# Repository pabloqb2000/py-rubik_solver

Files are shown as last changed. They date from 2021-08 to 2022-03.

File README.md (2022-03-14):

# Python solver for a rubik's cube
This project implements the logic for recognizing, storing, solving and visualizing a cube.

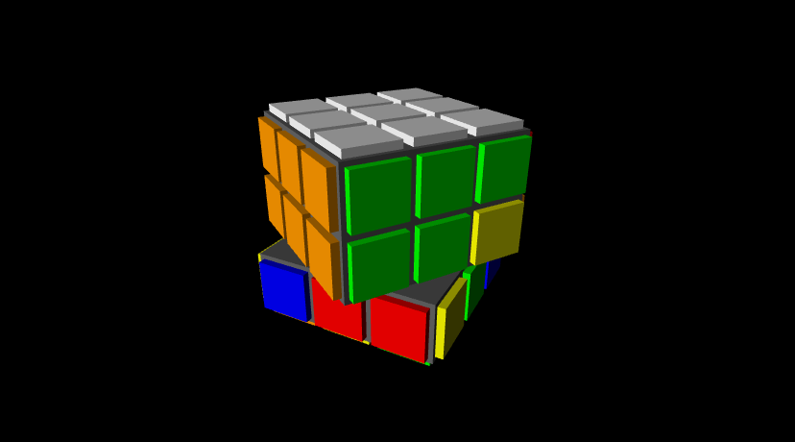
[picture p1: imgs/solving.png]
solving the cube image


## Robot

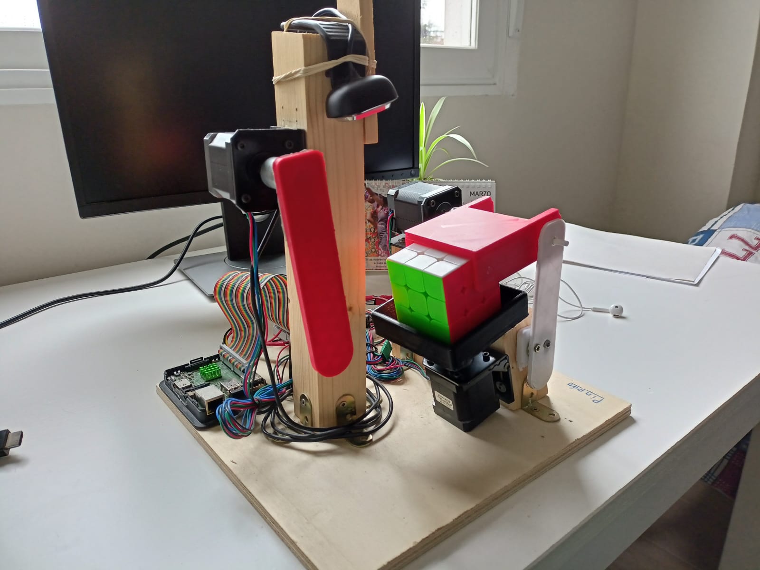
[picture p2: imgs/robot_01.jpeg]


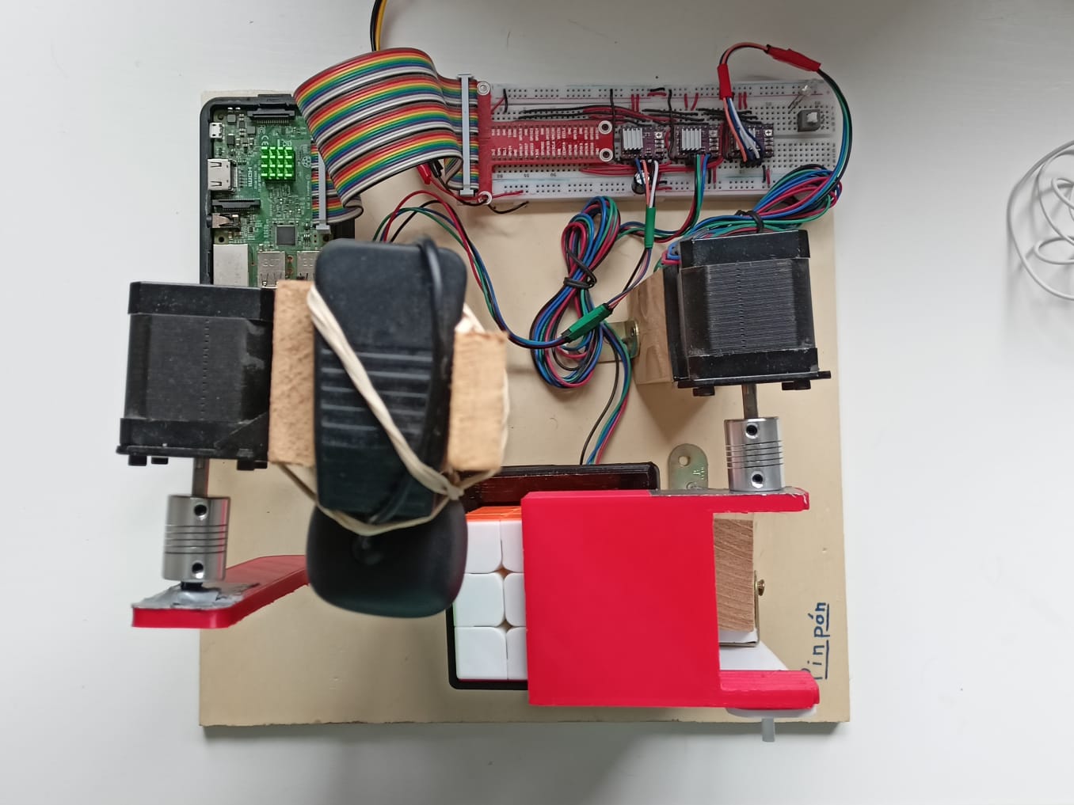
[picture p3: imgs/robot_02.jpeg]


## Demo

You can see the robot in speed up action here:

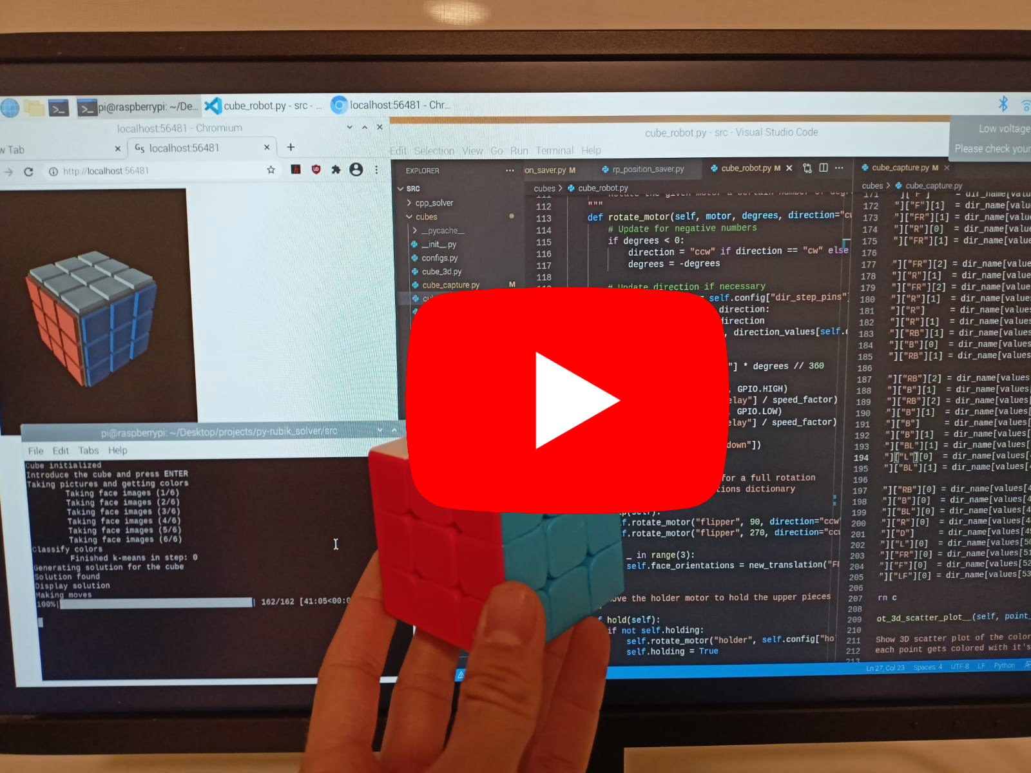
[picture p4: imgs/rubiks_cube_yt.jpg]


Or die whatching the raw full 43 minutes it takes to fully solve the cube here:

<a href="https://www.youtube.com/watch?v=FDxR2-XFLAM">Speed up video</a>

## Table of contents
- [Python solver for a rubik's cube](#python-solver-for-a-rubik-s-cube)
  * [Robot](#robot)
  * [Demo](#demo)
  * [Usage](#usage)
  * [Requirements](#requirements)
  * [Implementation](#implementation)
  * [Cubes directory](#cubes-directory)
    + [configs.py](#configspy)
    + [cube.py](#cubepy)
    + [cube_3d.py](#cube_3dpy)
    + [cube_capture.py](#cube_capturepy)
    + [cube_robot.py](#cube_robotpy)
    + [util.py](#utilpy)
  * [Saved positions directory](#saved-positions-directory)
  * [Solvers directory](#solvers-directory)
    + [cube_solver.py](#cube_solverpy)
    + [simple_solver.py](#simple_solverpy)
    + [simple_solver_2.py](#simple_solver_2py)
    + [iddfs.py](#iddfspy)
    + [thistlethwaite_solver.py](#thistlethwaite_solverpy)
  * [Hardware and wiring](#hardware-and-wiring)
  * [Appendix](#appendix)
  * [Notes](#notes)

## Usage
To use this program you need to execute the following commands inside de `src` folder
- For detecting the cube colors from a web cam and solving the cube:

    ```python detect_and_solve.py```
- For visualizing a solution of a randomly scrambled cube:

    ```python visualizer.py```
- For getting some statistics:

    ```python stats.py```
## Requirements
This project has been developed in _python 3.8.10_ but there is no reason it shouldn't work in _python 3.7_ or later.
You will also need a recent version of _numpy_, _tqdm_ and _vpython 7_ or later, those can be installed with:

```pip install numpy vpython tqdm```

## Implementation

This project is divided in three different directories:
- **cubes/** which contains all the logic for storing, visualizing and moving a cube
- **saved positions/** used to calibrate the raspberry pi camera
- **solvers/** where I store the different solvers I've implemented

And three main files:
- **detect_and_solve.py**: used to detect a cube with a webcam, find a solution and move the cube to finally solve it.
- **stas.py**: used to calculate some statistics about the different solvers, their speeds and the average number of total moves used.
- **visualizer.py**: used to scramble a virtual cube, find a solution and display the cube and the moves until the cube gets solved. 

## Cubes directory
### configs.py
This file contains general configuration parameters mostly related to the **default** visual representation of the cube:
- The default colors
- The number of fps
- The time taken to reproduce each move
- Time to wait between moves
- Speed factor
- And more

### cube.py
This file contains the ```Cube``` class, which implements a data structure for storing the pieces of the cube and some functions for rotating the faces of the cube. It also implements the possibility to shuffle the cube on creation and the possibility of recording a list of moves made in the cube, this is used for generating a solution.

The main functions implemented in this class are:
- ```move(move, n=1, record=True)```: where _move_ should be a string representing the face to move and _n_ is the number of 90 degree rotations to perform (2 is half turn and 3 or -1 is a turn to the other side). The codes used for the _move_ are:
    - _"U", "F", "R", "B", "L", "D"_ for individual faces.
    - _"UD", "FB", "RL"_ for the middle faces.
    - _"UU", "FF", "RR"_ for rotations of the whole cube along this axis.
    
- ```rotate(axis, n=1)```: this has the same effect as using ```move``` with _"UU", "FF", "RR"_ but these moves are never recorded.
- ```is_solved()```: checks whether the cube equals the solved cube. Keep in mind that this function will return ```False``` even if the cube is solved but faces a different way.
- ```copy()```: creates a _deep_copy_ of the cube. The copy is completely independent of the original cube.

### cube_3d.py
This file implements the ```Cube3D``` class, which directly inherits from the ```Cube``` class. This class overrides the ```__init__``` and ```move``` functions to first create all the cubes necessary to represent the rubiks cube in 3D and then animate them each time any face is moved.

### cube_capture.py
This file contains:
- An implementation for the `k_means` algorithm. This is an **unsupervised learning algorithm** used to classify the colors of the 54 stickers of the cube and separete them in 6 groups of 9 colors each, one group for each face.
- The ```CubeCapture``` class, which contains the logic for capturing the cube using the raspberry pi motors and webcam. The main method this class contains is the ```capture_cube``` method, this method takes care of calling the appropiate methods for:
    - Rotating the cube and taking the photos
    - Extract the colors from the center of the faces in the photos
    - Plot this colors on a 3D scatter plot if debug mode is enabled
    - Classify this colors using the `k_means` algorithm in 6 groups
    - Generate a cube structure from this classification of the colors

### cube_robot.py
This file contains the `CubeRobot` class, used to setup and move the motors on the raspberry pi. It encapsulates the motors movements in the method `move`, which is equivalent to the method move of the `Cube` class.

It also contains some configuration parameters related to the physical robot, like the numbers of the pins the motors are connected to, the speed of the movements and more.

### util.py
In this file we store different _lists_ and _dictionaries_ used in the project such as a solved cube structure, a list of the directions, a _function_ for generating random moves, ...

## Saved positions directory
This directory is simple, it just contains the `position_saver.py` file, which is used to calibrate the position of the faces seen by the camera. You just run it from the main folder with `python saved_positions/position_saver.py`, double click on the center of each piece, hit `space` to save the changes to `position_01.npy` and hit `Esc` to quit.

## Solvers directory
### cube_solver.py
This file implements the ```CubeSolver``` class, which acts as an abstract class for all the other solving algorithms. It only takes care of taking some measures for statistics.
### simple_solver.py
This is the first solving algorithm implemented, it's the usual _beginer_ algorithm for anyone learning how to solve the rubiks cube. It's implemented on a really naive way, and it's far from optimal in terms of the number of steps of the solution. It was just a proof of concept and my goal is to implement a better, more efficient version of this class in the future.

In my personal computer this algorithm takes ```1.78 ms``` on average to compute a solution, and the solutions have ```205.6``` steps on average. Again these results are far from good, but this was just a proof of concept.

The process of the algorithm is separated in different steps, which are:
- *solve_first_cross*: solves the cross on the _UP_ face
- *solve_first_corners*: solves the corners on the _UP_ face
- *solve_second_row*: solves the second _"crown"_ or the second row
- *solve_second_cross*: creates a cross on the _DOWN_ face
- *orientate_2nd_cross*: positions correctly the pieces inside the cross on the _DOWN_ face
- *solve_second_corners*: positions correctly the corners in the _DOWN_ face
- *orientate_2nd_corners*: rotates correctly the corners in the _DOWN_ face
- *reorient_cube*: rotates the whole cube so that the _UP_ face is facing up and the _FRONT_ face if facing front

### simple_solver_2.py
This file implements an optimization of the `simple_solver`, it just takes the `simple_solver` solution, eliminates the full cube rotations and simplifies the movements that can be unified.

### iddfs.py
This file just implements _iterative deepening depth first search_, a path finding algorithm to find the fastests secuences of moves that should be taken to reach a goal. This is a brute force algorithm and it would take ages to find the fastest solution for a cube, instead this is used by the thistlethwaite's algorithm.

### thistlethwaite_solver.py
More information about how this algorithm works can be found in the references.

This is an unfinished file, my idea was to implement this algorithm, but after some testing, python is too slow to run this algorithm in a reasonable amount of time. That's why I decided to implement a cpp version of this algorithm, but the cpp version just didn't work on the final step so, since I was running out of time, I decided to keep the naive raw `simple_solver` approach. Of course anyone is encouraged to try an implement the test functions for the first 3 solving groups.

## Hardware and wiring
<img src="https://raw.githubusercontent.com/pabloqb2000/py-rubik_solver/main/imgs/robot_03.jpeg" alt="Speed up video" width="500"/>

For this project I used:
- A Raspberry pi 3 model B v1.2
- 3 stepper motors (17HS19-2004s1)
- 3 step motor drivers (DRV8825)
- A usb webcam
- A 12V power supply for the motors
- A 100uF capacitor
- A breadboard and wires
- Some adaptors to connect the motors to the pieces
- 3D printed parts (available in the **stl/** directory)
- Wood and screws

For the wiring I followed this 2 tutorials:
- [How to fully set up each motor](https://www.rototron.info/raspberry-pi-stepper-motor-tutorial/)
- [How to connect multiple motors](https://forum.pololu.com/t/controlling-two-stepper-motors-with-two-ics-and-one-raspberry-pi-3b/16428/3)

## Appendix

Interesting video on rubik's cube solving algorithms [https://www.youtube.com/watch?v=ZtlMkzix7Bw](https://www.youtube.com/watch?v=ZtlMkzix7Bw)

The implementation the guy on the video made [https://github.com/benbotto/rubiks-cube-cracker](https://github.com/benbotto/rubiks-cube-cracker)

His medium post [https://medium.com/](https://medium.com/@benjamin.botto/sequentially-indexing-permutations-a-linear-algorithm-for-computing-lexicographic-rank-a22220ffd6e3)

Further information aboutn the thistlethwaite algorithm can be found in his GitHub readme, and post.

The idea for the robot I got it from [here](https://www.youtube.com/watch?v=awxGJ7aVk4g)

## Notes
There obviously are more efficient data structures to store the cube, faster algorithms to solve it, better physical robots. This is just the approach I found most intuitive and the one I decided to take the challenge and actually code it. **Any improvement on this code and design is more than wellcome**. 

Use this code as you wish, just let me know if you do, **I'll love to hear what you are up to!**

If you have any _doubts/comments/suggestions/anything_ please let my know via email at ```polqb2000@gmail.com``` or at the email in my profile.

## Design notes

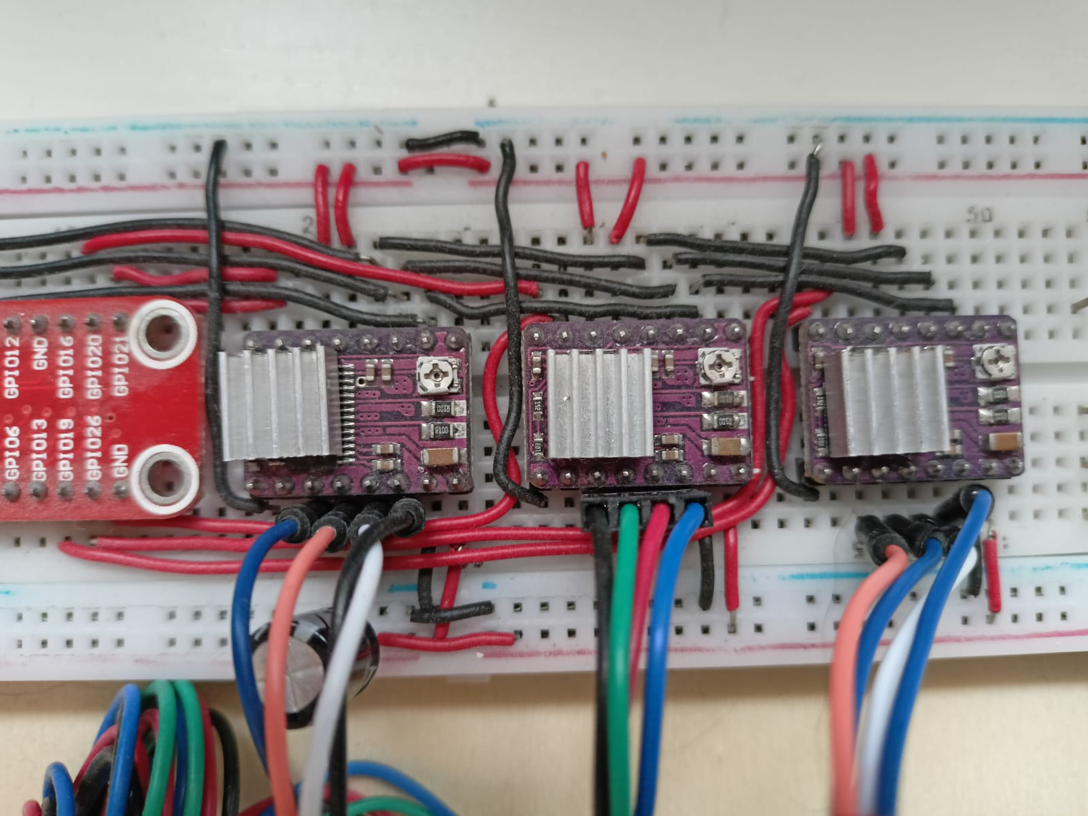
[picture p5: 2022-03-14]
imgs/robot_03.jpeg

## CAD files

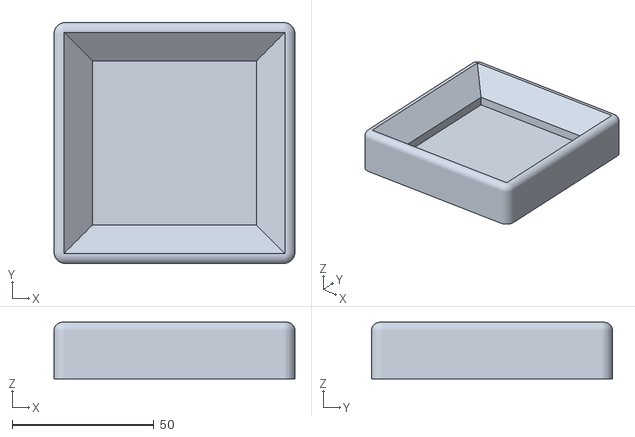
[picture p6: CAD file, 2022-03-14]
stl/Plate.stl
85.0 x 85.0 x 20.0

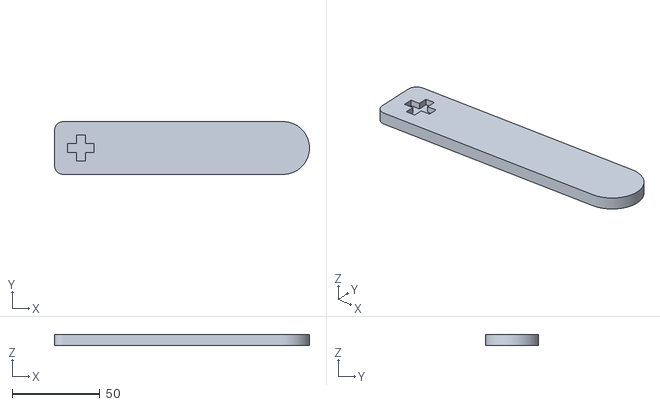
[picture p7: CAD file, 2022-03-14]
stl/Fliper.stl
145.0 x 30.0 x 6.00

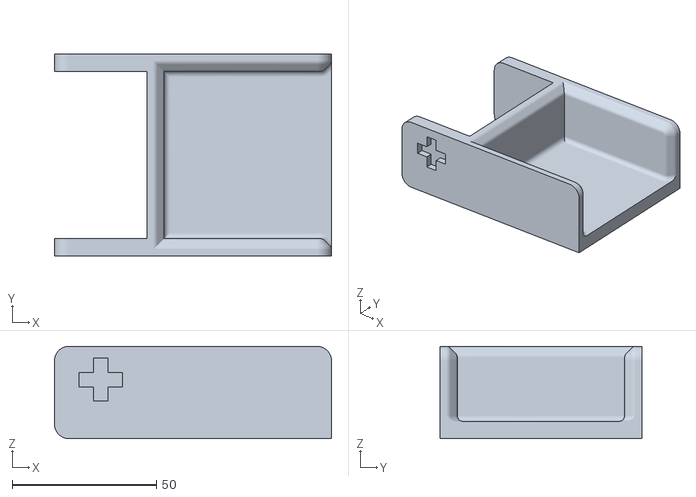
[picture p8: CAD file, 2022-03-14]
stl/Holder.stl
96.0 x 70.0 x 32.0

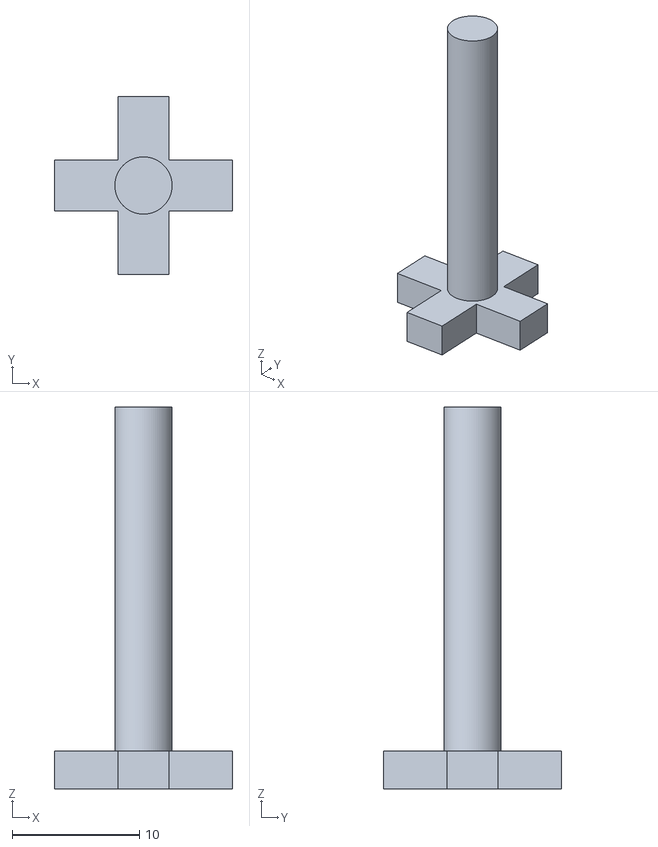
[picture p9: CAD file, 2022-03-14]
stl/Stick.stl
14.0 x 14.0 x 30.0

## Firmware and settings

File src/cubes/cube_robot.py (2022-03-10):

from cubes.util import *
import RPi.GPIO as GPIO
from time import sleep

resolution_values = {1:  (0, 0, 0),
                     2:  (1, 0, 0),
                     4:  (0, 1, 0),
                     8:  (1, 1, 0),
                     16: (0, 0, 1),
                     32: (1, 0, 1)}
motors = ["plate", "holder", "flipper"]
direction_values = {
    "cw": 1,
    "ccw": 0,
}

default_config = {
    "spr": 200,
    "base_delay": 0.0208 / 8,
    "cool_down": 0.1,
    "mode_pins": (14, 15, 18),
    "dir_step_pins": {
        "plate":   (16, 26),
        "holder":  (13, 19),
        "flipper": (20, 21),
    },
    "flip_speed": 0.05,
    "extra_plate_turn": 4,
    "extra_hold_turn": 6,
    "resolution": 32,
    "holder_degrees": 80,
    "holder_direction": "cw",
}

def inv(dir):
    return dir+'P' if dir[-1] != 'P' else dir[:-1]

def new_translation(dir, translate_dict):
    """
        Auxiliary function for the eliminate rotations function
        it returns the appropriate update for the translation dictionary
        given a rotation
    """
    new_translate_dict = translate_dict.copy()

    dir_new, n = translate_dict[dir], 3 if len(translate_dict[dir]) > 2 else 1
    d = dir_new[:2]

    if dir == "UU":
        new_translate_dict["RR"] = translate_dict["FF"]
        new_translate_dict["FF"] = inv(translate_dict["RR"])
    elif dir == "FF":
        new_translate_dict["UU"] = translate_dict["RR"]
        new_translate_dict["RR"] = inv(translate_dict["UU"])
    elif dir == "RR":
        new_translate_dict["UU"] = translate_dict["FF"]
        new_translate_dict["FF"] = inv(translate_dict["UU"])
    
    for _ in range(n):
        if d == "UU":
            new_translate_dict["F"] = translate_dict["R"]
            new_translate_dict["R"] = translate_dict["B"]
            new_translate_dict["B"] = translate_dict["L"]
            new_translate_dict["L"] = translate_dict["F"]
        elif d == "FF":
            new_translate_dict["U"] = translate_dict["L"]
            new_translate_dict["L"] = translate_dict["D"]
            new_translate_dict["D"] = translate_dict["R"]
            new_translate_dict["R"] = translate_dict["U"]
        elif d == "RR":
            new_translate_dict["U"] = translate_dict["F"]
            new_translate_dict["F"] = translate_dict["D"]
            new_translate_dict["D"] = translate_dict["B"]
            new_translate_dict["B"] = translate_dict["U"]
        for dn in direction_names:
            translate_dict[dn] = new_translate_dict[dn]
    return new_translate_dict


class CubeRobot:
    """
        Save cube configurations and setup pins for the movement of the motors
    """
    def __init__(self, config=default_config, speed=1):
        config["base_delay"] /= config["resolution"]
        config["delay"] = config["base_delay"] / speed
        config["spr"] *= config["resolution"]
        self.config = config
        self.dir = {motor: "cw" for motor in motors}
        self.holding = True

        self.pins_setup()
        self.face_orientations = {d: d for d in direction_names + ['UU', 'FF', 'RR']}

    """
        Setup the pins that are going to be used
    """
    def pins_setup(self):
        config = self.config

        GPIO.setmode(GPIO.BCM)
        GPIO.setup(config["mode_pins"], GPIO.OUT)
        GPIO.output(config["mode_pins"], resolution_values[config["resolution"]])
        for motor in motors:
            dir_pin, step_pin = config["dir_step_pins"][motor]
            GPIO.setup(dir_pin, GPIO.OUT)
            GPIO.setup(step_pin, GPIO.OUT)
            GPIO.output(dir_pin, direction_values[self.dir[motor]])

    """
        Rotate the given motor a certain number of degrees (0 - 360) in the given direction
    """
    def rotate_motor(self, motor, degrees, direction="cw", speed_factor=1):
        # Update for negative numbers
        if degrees < 0:
            direction = "ccw" if direction == "cw" else "cw"
            degrees = -degrees

        # Update direction if necessary
        dir_pin, step_pin = self.config["dir_step_pins"][motor]
        if self.dir[motor] != direction:
            self.dir[motor] = direction
            GPIO.output(dir_pin, direction_values[self.dir[motor]])

        # Rotate motor
        steps = self.config["spr"] * degrees // 360
        for _ in range(steps):
            GPIO.output(step_pin, GPIO.HIGH)
            sleep(self.config["delay"] / speed_factor)
            GPIO.output(step_pin, GPIO.LOW)
            sleep(self.config["delay"] / speed_factor)

        sleep(self.config["cool_down"])

    """
        Move the flipper motor for a full rotation
        And update the orientations dictionary
    """
    def flip(self):
        self.rotate_motor("flipper", 90, direction="ccw", speed_factor=self.config["flip_speed"])
        self.rotate_motor("flipper", 270, direction="ccw", speed_factor=4)
        
        for _ in range(3):
            self.face_orientations = new_translation("FF", self.face_orientations)

    """
        Move the holder motor to hold the upper pieces
    """
    def hold(self):
        if not self.holding:
            self.rotate_motor("holder", self.config["holder_degrees"] + self.config["extra_hold_turn"], self.config["holder_direction"], speed_factor=2)
            self.holding = True

    """
        Move the holder motor to release the upper pieces
    """
    def un_hold(self):
        if self.holding:
            self.rotate_motor("holder", self.config["holder_degrees"],
                              "cw" if self.config["holder_direction"] == "ccw" else "ccw", speed_factor=2)
            self.holding = False

    """
        Move the plate motor clockwise for n*90 degrees (in the fastest direction)
        And update the orientations dictionary
    """
    def move_plate(self, n):
        n %= 4
        if n == 0:
            return
        dir = "ccw" if n != 3 else "cw"
        angle = n*90 if n != 3 else 90
        if self.holding:
            angle += self.config["extra_plate_turn"] * (2 if n == 3 else 1)
        self.rotate_motor("plate", angle, dir, speed_factor=4)
        if self.holding and self.config["extra_plate_turn"] > 0:
            self.un_hold()
            self.rotate_motor("plate", -self.config["extra_plate_turn"] * (2 if n == 3 else 1), dir, speed_factor=4)
            self.hold()

        # Update the orientations dictionary
        if not self.holding:
            for _ in range((-n) % 4):
                self.face_orientations = new_translation("UU", self.face_orientations)

    """
        Apply a list of moves
        Each move should be a tuple like: ("U", -1)
    """
    def moves(self, moves):
        for dir, n in moves:
            self.move(dir, n)
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

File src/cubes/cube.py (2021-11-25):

from cubes.util import *
import copy


class Cube:
    """
        Initialize the cube structure
        Shuffle and copy the cube if necessary
    """
    def __init__(self,
                 cube_dict=solved_cube_dict,
                 shuffle=False,
                 n_shuffles=200,
                 record=False,
                 do_copy=True,
                 moves_made=[]):
        self.cube_dict = copy.deepcopy(cube_dict) if do_copy else cube_dict
        self.record = record
        self.moves_made = moves_made.copy() if do_copy else moves_made

        if shuffle:
            self.moves([random_move() for _ in range(n_shuffles)])

    """
        Return a completely independent copy of the cube
    """
    def copy(self):
        return Cube(self.cube_dict, shuffle=False, record=self.record, moves_made=self.moves_made)

    """
        Check if the cube is solved
    """
    def is_solved(self):
        return self.cube_dict == solved_cube_dict

    """
        Return a list of the side pieces
    """
    def get_sides(self, h=0):
        sides = [self.cube_dict["U"][s] for s in side_names] + \
                [self.cube_dict[s][ss] for s, ss in zip(side_names, side_names_roll)] + \
                [self.cube_dict["D"][s] for s in side_names]
        return sides[4 * h:]

    """
        Rotate the whole cube along an axis without recording the moves
        The axis should be "U", "F", "R", "B", "L", "D"
    """
    def rotate(self, axis, n=1):
        opposite = {"U": "D", "F": "B", "R": "L"}
        self.moves([
            (axis, n),
            (axis + opposite[axis], n),
            (opposite[axis], -n)
        ], record=False)

    """
        Apply a list of moves
        Each move should be a tuple like: ("U", -1)
    """
    def moves(self, moves, record=True):
        for move, n in moves:
            self.move(move, n, record=record)

    """
        Apply a move to one of the faces
        Move should be a tuple or a string indicating the move
        The possible moves are: 
            - "U", "F", "R", "B", "L", "D" for individual faces.
            - "UD", "FB", "RL" for the middle faces.
            - "UU", "FF", "RR" for rotations of the whole cube along this axis.
        n should be the number of 90 degree rotations to apply
    """
    def move(self, move, n=1, record=True):
        if type(move) == tuple:
            move, n = move
            
        n %= 4
        if n == 0:
            return

        if self.record and record:
            self.moves_made.append((move, n))

        if move == "U":
            for _ in range(n):
                self.moveU()
        elif move == "F":
            for _ in range(n):
                self.moveF()
        elif move == "R":
            for _ in range(n):
                self.moveR()
        elif move == "B":
            for _ in range(n):
                self.moveB()
        elif move == "L":
            for _ in range(n):
                self.moveL()
        elif move == "D":
            for _ in range(n):
                self.moveD()
        elif move == "UD":
            for _ in range(n):
                self.moveUD()
        elif move == "FB":
            for _ in range(n):
                self.moveFB()
        elif move == "RL":
            for _ in range(n):
                self.moveRL()
        elif len(move) == 2 and move[0] == move[1]:
            self.rotate(move[0], n)
        return self

    """
        Move UP face anticlockwise
    """
    def moveU(self):
        c = self.cube_dict["U"]

        c["F"], c["R"], c["B"], c["L"] = \
            c["L"], c["F"], c["R"], c["B"]

        c["FR"], c["RB"], c["BL"], c["LF"] = \
            c["LF"], c["FR"], c["RB"], c["BL"]

    """
        Move FRONT face anticlockwise
    """
    def moveF(self):
        c = self.cube_dict

        c["U"]["F"], c["L"]["F"], c["D"]["F"], c["F"]["R"] = \
            c["F"]["R"][::-1], c["U"]["F"], c["L"]["F"], c["D"]["F"][::-1]

        c["U"]["LF"], c["D"]["LF"], c["D"]["FR"], c["U"]["FR"] = \
            [c["U"]["FR"][2], c["U"]["FR"][0], c["U"]["FR"][1]], \
            [c["U"]["LF"][1], c["U"]["LF"][0], c["U"]["LF"][2]], \
            [c["D"]["LF"][1], c["D"]["LF"][2], c["D"]["LF"][0]], \
            [c["D"]["FR"][2], c["D"]["FR"][1], c["D"]["FR"][0]]

    """
        Move RIGHT face anticlockwise
    """
    def moveR(self):
        c = self.cube_dict

        c["U"]["R"], c["F"]["R"], c["D"]["R"], c["R"]["B"] = \
            c["R"]["B"][::-1], c["U"]["R"], c["F"]["R"], c["D"]["R"][::-1]

        c["U"]["FR"], c["D"]["FR"], c["D"]["RB"], c["U"]["RB"] = \
            [c["U"]["RB"][2], c["U"]["RB"][0], c["U"]["RB"][1]], \
            [c["U"]["FR"][1], c["U"]["FR"][0], c["U"]["FR"][2]], \
            [c["D"]["FR"][1], c["D"]["FR"][2], c["D"]["FR"][0]], \
            [c["D"]["RB"][2], c["D"]["RB"][1], c["D"]["RB"][0]]

    """
        Move BACK face anticlockwise
    """
    def moveB(self):
        c = self.cube_dict

        c["U"]["B"], c["R"]["B"], c["D"]["B"], c["B"]["L"] = \
            c["B"]["L"][::-1], c["U"]["B"], c["R"]["B"], c["D"]["B"][::-1]

        c["U"]["RB"], c["D"]["RB"], c["D"]["BL"], c["U"]["BL"] = \
            [c["U"]["BL"][2], c["U"]["BL"][0], c["U"]["BL"][1]], \
            [c["U"]["RB"][1], c["U"]["RB"][0], c["U"]["RB"][2]], \
            [c["D"]["RB"][1], c["D"]["RB"][2], c["D"]["RB"][0]], \
            [c["D"]["BL"][2], c["D"]["BL"][1], c["D"]["BL"][0]]

    """
        Move LEFT face anticlockwise
    """
    def moveL(self):
        c = self.cube_dict

        c["U"]["L"], c["B"]["L"], c["D"]["L"], c["L"]["F"] = \
            c["L"]["F"][::-1], c["U"]["L"], c["B"]["L"], c["D"]["L"][::-1]

        c["U"]["BL"], c["D"]["BL"], c["D"]["LF"], c["U"]["LF"] = \
            [c["U"]["LF"][2], c["U"]["LF"][0], c["U"]["LF"][1]], \
            [c["U"]["BL"][1], c["U"]["BL"][0], c["U"]["BL"][2]], \
            [c["D"]["BL"][1], c["D"]["BL"][2], c["D"]["BL"][0]], \
            [c["D"]["LF"][2], c["D"]["LF"][1], c["D"]["LF"][0]]

    """
        Move DOWN face anticlockwise
    """
    def moveD(self):
        c = self.cube_dict["D"]

        c["F"], c["R"], c["B"], c["L"] = \
            c["R"], c["B"], c["L"], c["F"]

        c["FR"], c["RB"], c["BL"], c["LF"] = \
            c["RB"], c["BL"], c["LF"], c["FR"]

    """
        Move the middle "crown" on the UP direction anticlockwise
    """
    def moveUD(self):
        c = self.cube_dict
        c["F"]["R"], c["R"]["B"], c["B"]["L"], c["L"]["F"] = \
            c["L"]["F"], c["F"]["R"], c["R"]["B"], c["B"]["L"]

        c["F"]["F"], c["R"]["R"], c["B"]["B"], c["L"]["L"] = \
            c["L"]["L"], c["F"]["F"], c["R"]["R"], c["B"]["B"]

    """
        Move the middle "crown" on the FRONT direction anticlockwise
    """
    def moveFB(self):
        c = self.cube_dict
        c["U"]["L"], c["D"]["L"], c["D"]["R"], c["U"]["R"] = \
            c["U"]["R"][::-1], c["U"]["L"][::-1], c["D"]["L"][::-1], c["D"]["R"][::-1]
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

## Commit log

2021-08-19 Changed velocity
2021-09-11 Added raspberry pi code
2021-11-26 Cambios raspberry
